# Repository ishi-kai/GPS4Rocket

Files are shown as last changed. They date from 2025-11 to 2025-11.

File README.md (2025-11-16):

# GPS System for Rocket
Commercially available GPS systems are not available for rockets.  
Therefore, we have created a full-scratch system.  

## Specification
- GPS Antenna
    - Use commercially available active antennas.
- [GPS Front End](https://github.com/ishi-kai/GPS4Rocket#GPS_FrontEnd)
    - MAX2769B-based GPS front-end board
- [Navigation Message Processor](https://github.com/ishi-kai/GPS4Rocket#Navigation_Message_Processor)
    - Operator to process IO data and navigation messages

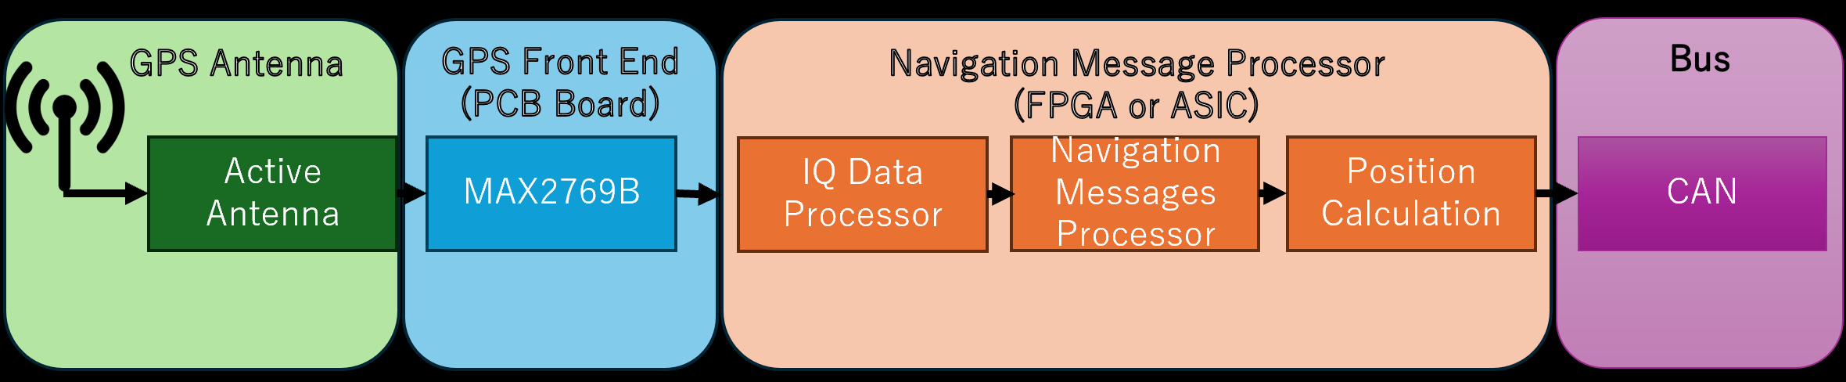
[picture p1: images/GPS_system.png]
GPS_System


## [GPS Front End Board](/GPS_FrontEnd/)
This is the hardware that handles the GPS front end. And This was created with KiCAD 9.  

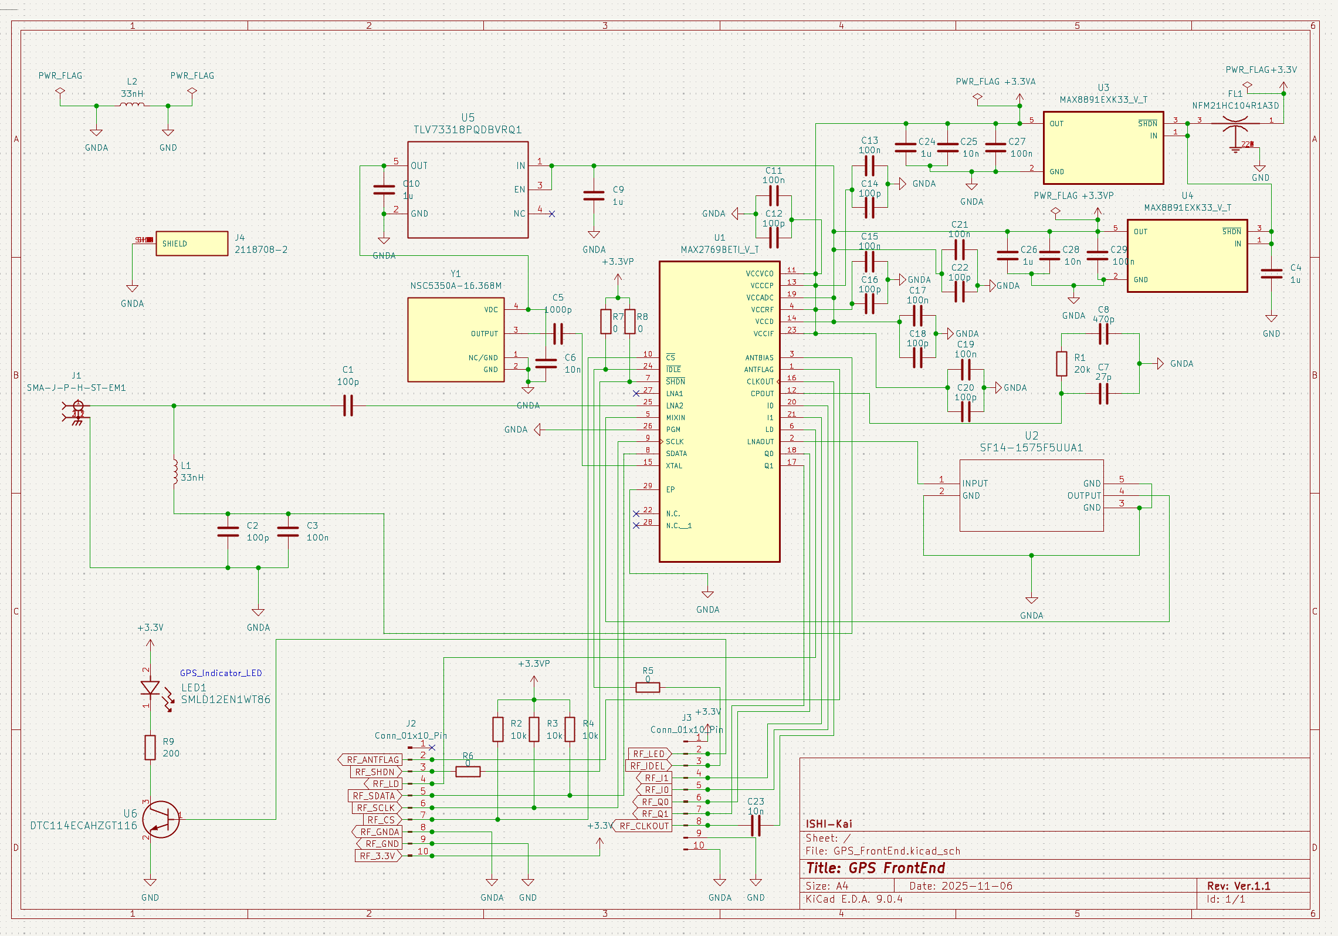
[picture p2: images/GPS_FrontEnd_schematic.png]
GPS_FrontEnd_schematic

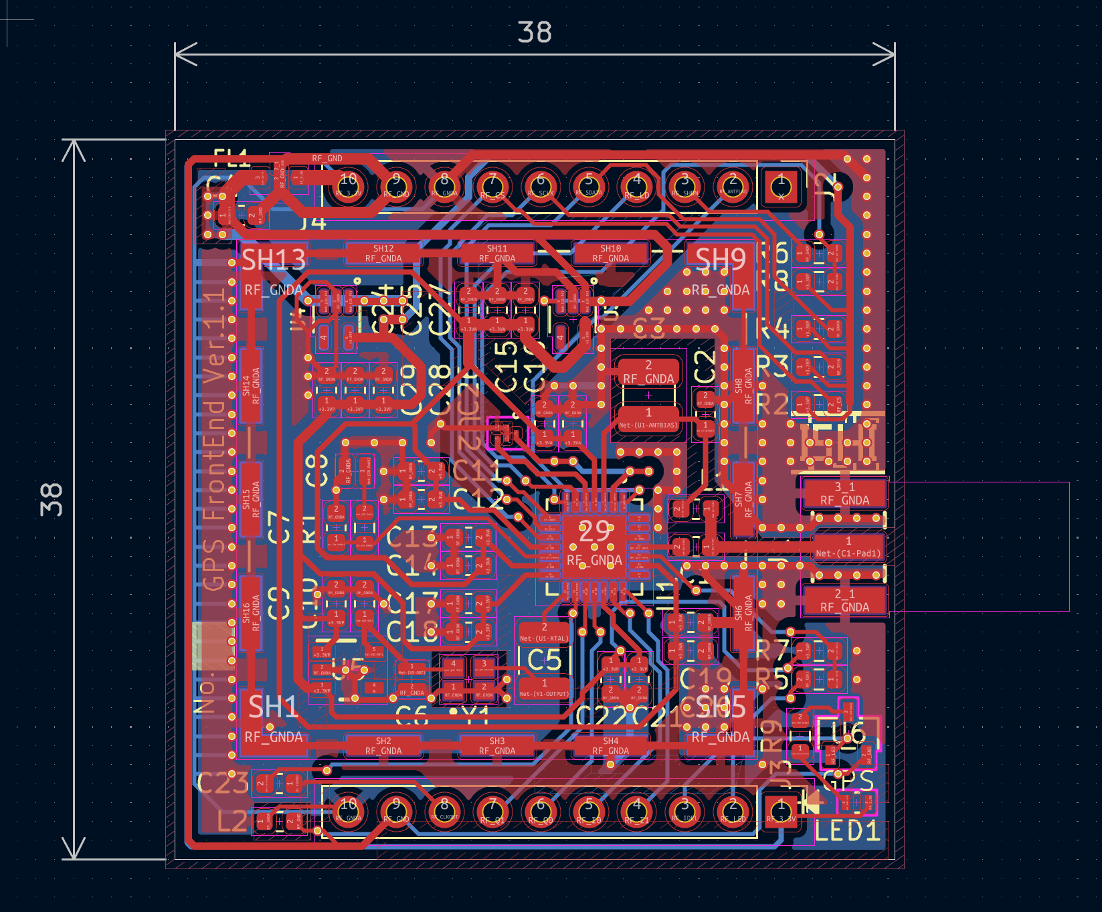
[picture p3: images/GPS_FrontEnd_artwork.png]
GPS_FrontEnd_artwork

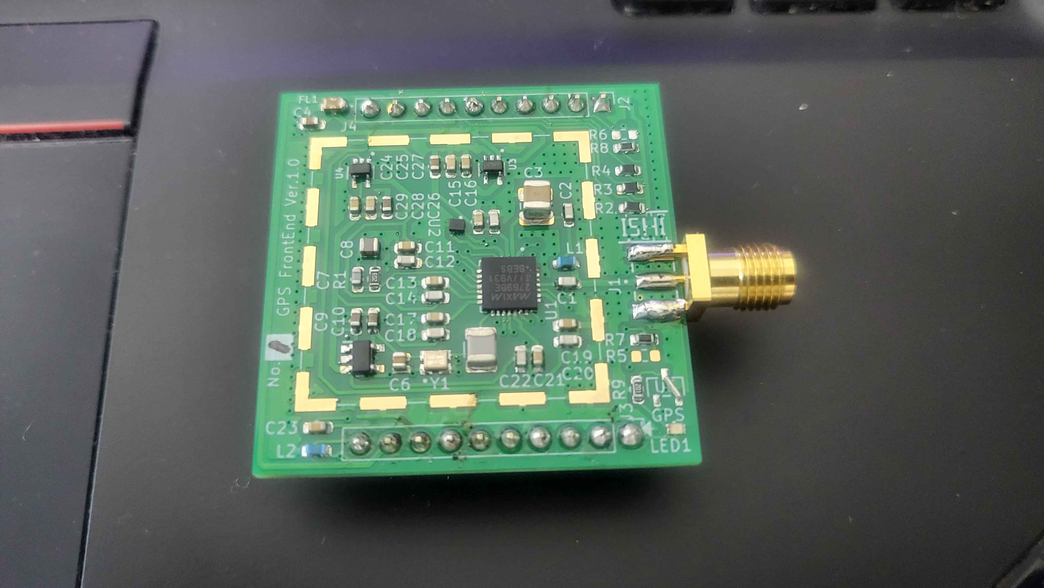
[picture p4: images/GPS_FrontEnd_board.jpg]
GPS_FrontEnd_board


## [Navigation Message Processor](/Navigation_Message_Processor/)

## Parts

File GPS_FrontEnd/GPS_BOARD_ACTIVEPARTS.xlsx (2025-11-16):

出荷時に原産国が変わる場合があります。
表示されているHTSUSおよびECCN情報は情報提供のみを目的としたもので、分類の正確性や信頼性を表明または保証するものではありません。すべての情報は「現状のまま」提供されており、予告なしに変更される場合があります。提供された情報の使用は、Digi-Keyに頼ることなく、ユーザーの責任において使用されるものとします。
インデックス | メーカー品番 | メーカー名 | 商品概要 | リードタイム | 入手性 | 在庫状況 | 仕損率 | リクエスト数量1 | パック数量1 | パックタイプ1 | Digi-Key品番1 | 単価1 | 金額1 | 最小発注数量1 | 客先参照品番 | リクエスト品番 | リードタイム（週） | データシート | 参照名 | 米国輸入関税 | メモ | 部品状況 | RoHSステータス | 湿度感度レベル（MSL） | ECCN | HTSUS | 原産国 | 環境規制対応 | オリジナル品番 | 画像 | 製品に関する注意事項
1 | MAX2769BETI/V+T | Analog Devices Inc./Maxim Integrated | RF RCVR GPS 1575.42MHZ 28TQFN |  | 1,961 | 在庫品目 |  | 1 | 1 | Cut Tape (CT) | 175-MAX2769BETI/V+TCT-ND | 11.32000 | $11.32 | 1 |  | 175-MAX2769BETI/V+TCT-ND | 10 | https://mm.digikey.com/Volume0/opasdata/d220001/medias/docus/1075/MAX2769B_PB.pdf |  | N/A |  | アクティブ | ROHS3対応 | 1（無制限） | 7A994 | 8542.39.0060 | Taiwan | https://www.maximintegrated.com/content/dam/files/design/emmi/rohs-certificate-of-compliance.pdf|https://www.maximintegrated.com/content/dam/files/design/emmi/reach-memo.pdf|https://www.maximintegrated.com/content/dam/files/design/emmi/red-phosphorous-statement.pdf | 175-MAX2769BETI/V+TCT-ND | https://mm.digikey.com/Volume0/opasdata/d220001/medias/images/6165/175%7E21-0140%7ETI%7E28.jpg | キャンセルや返品はできません.
2 | MAX8891EXK33/V+T | Analog Devices Inc./Maxim Integrated | IC REG LINEAR 3.3V 150MA SC-70-6 |  | 3,895 | 在庫品目 |  | 2 | 2 | Cut Tape (CT) | 175-MAX8891EXK33/V+TCT-ND | 2.11000 | $4.22 | 1 |  | 175-MAX8891EXK33/V+TCT-ND | 10 | https://www.analog.com/media/en/technical-documentation/data-sheets/MAX8891-MAX8892.pdf |  | N/A |  | アクティブ | ROHS3対応 | 1（無制限） | EAR99 | 8542.39.0090 | Malaysia | https://www.maximintegrated.com/content/dam/files/design/emmi/rohs-certificate-of-compliance.pdf|https://www.maximintegrated.com/content/dam/files/design/emmi/reach-memo.pdf | 175-MAX8891EXK33/V+TCT-ND | https://mm.digikey.com/Volume0/opasdata/d220001/medias/images/890/175-SC-70-5.jpg
3 | B39162B4348P810 | Qualcomm (RF front-end (RFFE) filters) | FILTER SAW 1.582GHZ 5-SMD |  | 778 | 在庫品目 |  | 1 | 1 | Cut Tape (CT) | B39162B4348P810CT-ND | 1.49000 | $1.49 | 1 |  | B39162B4348P810CT-ND | 8 | https://mm.digikey.com/Volume0/opasdata/d220001/medias/docus/925/B39162B4348P810.pdf |  | N/A |  | アクティブ | ROHS3対応 | 2A（4週間） | EAR99 | 8541.60.0080 | Singapore |  | B39162B4348P810CT-ND | https://mm.digikey.com/Volume0/opasdata/d220001/medias/images/2479/B7839%20Series.jpg
4 | SMA-J-P-H-ST-EM1 | Samtec Inc. | CONN SMA JACK STR 50OHM EDGE MNT | 2025年10月16日に入荷予定：1個 | 0 | 通常在庫 |  | 1 | 1 | Tray | SAM8857-ND | 2.43000 | $2.43 | 1 |  | SAM8857-ND | 6 | https://mm.digikey.com/Volume0/opasdata/d220001/medias/docus/6129/sma-j-p-x-st-em1-mkt.pdf |  | N/A |  | アクティブ | ROHS3対応 | 1（無制限） | EAR99 | 8536.69.4010 | Taiwan |  | SAM8857-ND | https://mm.digikey.com/Volume0/opasdata/d220001/medias/images/965/SMA-J-P-H-ST-EM1.JPG
5 | NSC5350A-16.368M | NDK (NIHON DEMPA KOGYO CO., LTD) | XTAL OSC TCXO 16.3680MHZ SMD |  | 867 | 在庫品目 |  | 1 | 1 | Cut Tape (CT) | 644-NSC5350A-16.368MCT-ND | 1.85000 | $1.85 | 1 |  | 644-NSC5350A-16.368MCT-ND | 24 | https://www.ndk.com/en/products/upload/lineup/pdf/NDKT03-00012_en.pdf |  | N/A |  | アクティブ | ROHS3対応 | 2（1年間） | EAR99 | 8542.39.0090 | Japan |  | 644-NSC5350A-16.368MCT-ND | https://mm.digikey.com/Volume0/opasdata/d220001/medias/images/55/MFG_NSC5350B-26M.jpg
6 | TLV73318PQDBVRQ1 | Texas Instruments | IC REG LINEAR 1.8V 300MA SOT23-5 |  | 16,868 | 在庫品目 |  | 1 | 1 | Cut Tape (CT) | 296-TLV73318PQDBVRQ1CT-ND | 0.45000 | $0.45 | 1 |  | 296-TLV73318PQDBVRQ1CT-ND | 12 | https://www.ti.com/general/docs/suppproductinfo.tsp?distId=10 |  | N/A |  | アクティブ | ROHS3対応 | 1（無制限） | EAR99 | 8542.39.0090 | Philippines |  | 296-TLV73318PQDBVRQ1CT-ND | https://mm.digikey.com/Volume0/opasdata/d220001/medias/images/5347/296%7E4214839%7EDBV%7E5.JPG
7 | SF14-1575F5UUA1 | KYOCERA AVX | FILTER SAW 1.575GHZ 5-SMD |  | 8,991 | 個在庫あり - 非在庫保有商品 |  | 1 | 1 | Cut Tape (CT) | 478-SF14-1575F5UUA1CT-ND | 0.61000 | $0.61 | 1 |  | 478-SF14-1575F5UUA1CT-ND | 16 | https://mm.digikey.com/Volume0/opasdata/d220001/medias/docus/6164/SF14_Saw_Filters.pdf |  | N/A |  | 生産中止品 | ROHS3対応 | 3（168時間） | 7A994 | 8541.60.0080 | Japan | https://ele.kyocera.com/assets/products/saw-device/environment/RoHS_SF14.pdf|https://ele.kyocera.com/assets/products/saw-device/environment/REACH_SF14.pdf | 478-SF14-1575F5UUA1CT-ND | https://mm.digikey.com/Volume0/opasdata/d220001/medias/images/2935/SF14%20Series.jpg
8 | DTC114ECAHZGT116 | Rohm Semiconductor | TRANS PREBIAS NPN 0.1A SST3 |  | 2,933 | 在庫品目 |  | 1 | 1 | Cut Tape (CT) | DTC114ECAHZGT116CT-ND | 0.17000 | $0.17 | 1 |  | DTC114ECAHZGT116CT-ND | 18 | https://www.rohm.co.jp/datasheet?p=DTC114ECAHZG&dist=Digi-key&media=referral&campaign=Digi-key |  | N/A |  | アクティブ | ROHS3対応 | 1（無制限） | EAR99 | 8541.21.0075 | South Korea | https://fscdn.rohm.com/en/techdata_basic/transistor/anti_whisker/TR_Whisker-e.pdf|https://fscdn.rohm.com/en/techdata_basic/transistor/esd/ESD_TR-DTC114ECAHZG-e.pdf|https://fscdn.rohm.com/en/techdata_basic/transistor/msl/TR_MSL-e.pdf | DTC114ECAHZGT116CT-ND | https://mm.digikey.com/Volume0/opasdata/d220001/medias/images/6347/846%7ESST3%7ESST%7E3.jpg
9 | 2118708-2 | TE Connectivity AMP Connectors | RF SHIELD 1.032"X1.032" SMD 1PC |  | 9,237 | 在庫品目 |  | 1 | 1 | Cut Tape (CT) | A126142CT-ND | 1.05000 | $1.05 | 1 |  | A126142CT-ND | 5 | https://www.te.com/commerce/DocumentDelivery/DDEController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 |  | N/A |  | アクティブ | RoHS対応 | 適用外 | EAR99 | 8529.90.9800 | China |  | A126142CT-ND | https://mm.digikey.com/Volume0/opasdata/d220001/medias/images/2521/MFG_2118708-2.jpg

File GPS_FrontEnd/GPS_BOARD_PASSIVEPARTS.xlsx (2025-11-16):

出荷時に原産国が変わる場合があります。
表示されているHTSUSおよびECCN情報は情報提供のみを目的としたもので、分類の正確性や信頼性を表明または保証するものではありません。すべての情報は「現状のまま」提供されており、予告なしに変更される場合があります。提供された情報の使用は、Digi-Keyに頼ることなく、ユーザーの責任において使用されるものとします。
インデックス | メーカー品番 | メーカー名 | 商品概要 | リードタイム | 入手性 | 在庫状況 | 仕損率 | リクエスト数量1 | パック数量1 | パックタイプ1 | Digi-Key品番1 | 単価1 | 金額1 | 最小発注数量1 | 客先参照品番 | リクエスト品番 | リードタイム（週） | データシート | 参照名 | 米国輸入関税 | メモ | 部品状況 | RoHSステータス | 湿度感度レベル（MSL） | ECCN | HTSUS | 原産国 | 環境規制対応 | オリジナル品番 | 画像 | 製品に関する注意事項
1 | SMLD12EN1WT86C | Rohm Semiconductor | LONG LIFE TYPE MINI-MOLD CHIP LE |  | 1,099 | 在庫品目 |  | 1 | 1 | Cut Tape (CT) | 846-SMLD12EN1WT86CCT-ND | 0.56000 | $0.56 | 1 |  | 846-SMLD12EN1WT86CCT-ND | 10 | https://www.rohm.com/datasheet?p=SMLD12EN1W(C)&dist=Digi-Key&media=referral&campaign=Digi-Key |  | N/A |  | アクティブ | ROHS3対応 | 3（168時間） | EAR99 | 8541.41.0000 | China |  | 846-SMLD12EN1WT86CCT-ND | https://mm.digikey.com/Volume0/opasdata/d220001/medias/images/5739/MFG_SMLD12EN1WT86C.jpg
2 | KGQ15ACG1H101FT | KYOCERA AVX | CAP CER 100PF 50V NP0 0603 |  | 7,700 | 在庫品目 |  | 8 | 8 | Cut Tape (CT) | 478-KGQ15ACG1H101FTCT-ND | 0.33000 | $2.64 | 1 |  | 478-KGQ15ACG1H101FTCT-ND | 10 | https://datasheets.kyocera-avx.com/KGQ-Series.pdf |  | N/A |  | アクティブ | ROHS3対応 | 1（無制限） | EAR99 | 8532.24.0020 | China |  | 478-KGQ15ACG1H101FTCT-ND | https://mm.digikey.com/Volume0/opasdata/d220001/medias/images/775/0603-%281608-Metric%29-0%2C91mm.jpg
3 | 1111X104KW500X | Passive Plus | CAP CER 0.1UF 50V X7R 1111 |  | 84 | 在庫品目 |  | 1 | 1 | Cut Tape (CT) | 4363-1111X104KW500XCT-ND | 4.79000 | $4.79 | 1 |  | 4363-1111X104KW500XCT-ND | 16 | https://passiveplus.com/products/fixed-capacitors/hi-q-low-esr-capacitors/ |  | N/A |  | アクティブ | ROHS3対応 | 1（無制限） | EAR99 | 8532.24.0020 | United States |  | 4363-1111X104KW500XCT-ND | https://mm.digikey.com/Volume0/opasdata/d220001/medias/images/4846/MFG_4363_1111x.jpg
4 | KGQ32DCG2A102FT | KYOCERA AVX | CAP CER 1000PF 100V C0G/NP0 1210 |  | 1,299 | 在庫品目 |  | 1 | 1 | Cut Tape (CT) | 478-KGQ32DCG2A102FTCT-ND | 0.70000 | $0.70 | 1 |  | 478-KGQ32DCG2A102FTCT-ND | 10 | https://datasheets.kyocera-avx.com/KGQ-Series.pdf |  | N/A |  | アクティブ | ROHS3対応 | 1（無制限） | EAR99 | 8532.24.0020 | El Salvador |  | 478-KGQ32DCG2A102FTCT-ND | https://mm.digikey.com/Volume0/opasdata/d220001/medias/images/935/1210-%283225-Metric%29-1%2C40mm-N-Code.jpg
5 | 0505X103MP500 | Passive Plus | CAP CER 10000PF 50V X7R 0505 |  | 1,400 | 在庫品目 |  | 1 | 1 | Cut Tape (CT) | 4363-0505X103MP500CT-ND | 3.89000 | $3.89 | 1 |  | 4363-0505X103MP500CT-ND | 16 | https://passiveplus.com/products/fixed-capacitors/hi-q-low-esr-capacitors/ |  | N/A |  | アクティブ | ROHS3対応 | 1（無制限） | EAR99 | 8532.24.0020 | United States |  | 4363-0505X103MP500CT-ND | https://mm.digikey.com/Volume0/opasdata/d220001/medias/images/3971/MFG_0505X.jpg
6 | KGQ15ACG1H270FT | KYOCERA AVX | CAP CER 27PF 50V NP0 0603 |  | 9,087 | 在庫品目 |  | 1 | 1 | Cut Tape (CT) | 478-KGQ15ACG1H270FTCT-ND | 0.33000 | $0.33 | 1 |  | 478-KGQ15ACG1H270FTCT-ND | 10 | https://datasheets.kyocera-avx.com/KGQ-Series.pdf |  | N/A |  | アクティブ | ROHS3対応 | 1（無制限） | EAR99 | 8532.24.0020 | El Salvador |  | 478-KGQ15ACG1H270FTCT-ND | https://mm.digikey.com/Volume0/opasdata/d220001/medias/images/775/0603-%281608-Metric%29-0%2C91mm.jpg
7 | 050521500471FQTAF9LM | Knowles Syfer | 0505 SIZE - 2 SINTERED SILVER WI |  | 2,406 | 在庫品目 |  | 1 | 1 | Cut Tape (CT) | 1608-050521500471FQTAF9LMCT-ND | 1.69000 | $1.69 | 1 |  | 1608-050521500471FQTAF9LMCT-ND | 11 | https://www.knowlescapacitors.com/getattachment/ac79327c-78b2-4790-b841-4541dcd9a291/High-Power-RF |  | N/A |  | アクティブ | ROHS3対応 | 1（無制限） | EAR99 | 8532.24.0020 | China |  | 1608-050521500471FQTAF9LMCT-ND | https://mm.digikey.com/Volume0/opasdata/d220001/medias/images/5701/MFG_CxxAH2R2x-xN-X1B.jpg
8 | KAM15AR70J105KT | KYOCERA AVX | 0603 X7R 1UF10% 6.3V AEC-Q200 |  | 11,890 | 在庫品目 |  | 5 | 5 | Cut Tape (CT) | 478-KAM15AR70J105KTCT-ND | 0.16000 | $0.80 | 1 |  | 478-KAM15AR70J105KTCT-ND | 20 | https://mm.digikey.com/Volume0/opasdata/d220001/medias/docus/5789/KAM15AR70J105KT%20Datasheet.pdf |  | N/A |  | アクティブ | ROHS3対応 | 1（無制限） | EAR99 | 8532.24.0020 | Japan |  | 478-KAM15AR70J105KTCT-ND | https://mm.digikey.com/Volume0/opasdata/d220001/medias/images/4845/478_0603-%281608-Metric%29-0%2C90mm.jpg | キャンセルや返品はできません.
9 | 0603YC104J4T4A | KYOCERA AVX | CAP CER 0.1UF 16V X7R 0603 |  | 5,180 | 在庫品目 |  | 8 | 8 | Cut Tape (CT) | 478-KAM15AR71C104JMCT-ND | 0.33000 | $2.64 | 1 |  | 478-KAM15AR71C104JMCT-ND | 12 | https://datasheets.kyocera-avx.com/AutoMLCC.pdf |  | N/A |  | アクティブ | ROHS3対応 | 1（無制限） | EAR99 | 8532.24.0020 | El Salvador |  | 478-KAM15AR71C104JMCT-ND | https://mm.digikey.com/Volume0/opasdata/d220001/medias/images/4845/478_0603-%281608-Metric%29-0%2C90mm.jpg
10 | KAM15AR71C103JT | KYOCERA AVX | CAP CER 10000PF 16V X7R 0603 |  | 3,275 | 在庫品目 |  | 3 | 3 | Cut Tape (CT) | 478-KAM15AR71C103JTCT-ND | 0.23000 | $0.69 | 1 |  | 478-KAM15AR71C103JTCT-ND | 12 | https://datasheets.kyocera-avx.com/AutoMLCCKAM.pdf |  | N/A |  | アクティブ | ROHS3対応 | 1（無制限） | EAR99 | 8532.24.0020 | El Salvador |  | 478-KAM15AR71C103JTCT-ND | https://mm.digikey.com/Volume0/opasdata/d220001/medias/images/4845/478_0603-%281608-Metric%29-0%2C90mm.jpg
11 | LQW18AS33NG0ZD | Murata Electronics | FIXED IND 33NH 600MA 220MOHM SMD |  | 18,952 | 在庫品目 |  | 2 | 2 | Cut Tape (CT) | 490-15818-1-ND | 0.15000 | $0.30 | 1 |  | 490-15818-1-ND | 16 | https://search.murata.co.jp/Ceramy/image/img/P02/JELF243A-9139.pdf |  | N/A |  | アクティブ | ROHS3対応 | 1（無制限） | EAR99 | 8504.50.8000 | Japan |  | 490-15818-1-ND | https://mm.digikey.com/Volume0/opasdata/d220001/medias/images/2530/0603%20%281608%20Metric%29%20Wirewound.jpg
12 | ERA-3ARW203V | Panasonic Electronic Components | RES SMD 20K OHM 0.05% 1/10W 0603 |  | 11,946 | 在庫品目 |  | 1 | 1 | Cut Tape (CT) | P20KBECT-ND | 0.44000 | $0.44 | 1 |  | P20KBECT-ND | 12 | https://industrial.panasonic.com/cdbs/www-data/pdf/RDM0000/AOA0000C307.pdf |  | N/A |  | アクティブ | ROHS3対応 | 1（無制限） | EAR99 | 8533.21.0030 | Japan | https://industrial.panasonic.com/cdbs/www-cgi/auto-publishing.cgi?type=ROSU&region=WW&layer=4&cd=AOA0026 | P20KBECT-ND | https://mm.digikey.com/Volume0/opasdata/d220001/medias/images/2391/10-0603%20Resistor.jpg
13 | ERJ-PA3F1002V | Panasonic Electronic Components | RES SMD 10K OHM 1% 1/3W 0603 |  | 53,902 | 在庫品目 |  | 3 | 3 | Cut Tape (CT) | P10KBYCT-ND | 0.14000 | $0.42 | 1 |  | P10KBYCT-ND | 12 | https://industrial.panasonic.com/cdbs/www-data/pdf/RDO0000/AOA0000C331.pdf |  | N/A |  | アクティブ | ROHS3対応 | 1（無制限） | EAR99 | 8533.21.0030 | Japan | https://industrial.panasonic.com/cdbs/www-cgi/auto-publishing.cgi?type=ROSU&region=WW&layer=4&cd=AOA0002 | P10KBYCT-ND | https://mm.digikey.com/Volume0/opasdata/d220001/medias/images/4322/cut-tape-render.jpg
14 | ERJ-H3G0R00V | Panasonic Electronic Components | RES 0 OHM JUMPER 1A 0603 |  | 6,751 | 在庫品目 |  | 2 | 2 | Cut Tape (CT) | 10-ERJ-H3G0R00VCT-ND | 0.10000 | $0.20 | 1 |  | 10-ERJ-H3G0R00VCT-ND | 12 | https://industrial.panasonic.com/cdbs/www-data/pdf/RDQ0000/ast-ind-151033.pdf |  | N/A |  | アクティブ | ROHS3対応 | 1（無制限） | EAR99 | 8533.21.0030 | Japan |  | 10-ERJ-H3G0R00VCT-ND | https://mm.digikey.com/Volume0/opasdata/d220001/medias/images/2642/MFG_Panasonic-ERJ-Hxx-Series-Resistors-Photo.jpg
15 | ERJ-3GEYJ201V | Panasonic Electronic Components | RES SMD 200 OHM 5% 1/10W 0603 |  | 459,412 | 在庫品目 |  | 1 | 1 | Cut Tape (CT) | P200GCT-ND | 0.10000 | $0.10 | 1 |  | P200GCT-ND | 12 | https://industrial.panasonic.com/ww/products/pt/general-purpose-chip-resistors/models/ERJ3GEYJ201V |  | N/A |  | アクティブ | ROHS3対応 | 1（無制限） | EAR99 | 8533.21.0030 | China | https://industrial.panasonic.com/cdbs/www-cgi/auto-publishing.cgi?type=ROSU&region=WW&layer=4&cd=AOA0002 | P200GCT-ND | https://mm.digikey.com/Volume0/opasdata/d220001/medias/images/2606/MFG_ERJ-P6W%20Series.jpg
16 | NFM21HC104R1A3D | Murata Electronics | CAP FEEDTHRU 0.1UF 20% 10V 0805 |  | 7,950 | 在庫品目 |  | 1 | 1 | Cut Tape (CT) | 490-11838-1-ND | 0.29000 | $0.29 | 1 |  | 490-11838-1-ND | 12 | https://search.murata.co.jp/Ceramy/image/img/A01X/G101/ENG/NFM21HC104R1A3-01.pdf |  | N/A |  | アクティブ | ROHS3対応 | 1（無制限） | EAR99 | 8532.24.0020 | Japan |  | 490-11838-1-ND | https://mm.digikey.com/Volume0/opasdata/d220001/medias/images/4999/EMIFIL-NFM21-3PC-Pad-Black.JPG

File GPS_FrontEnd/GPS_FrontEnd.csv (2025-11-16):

Reference | Qty | Value | DNP | Exclude from BOM | Exclude from Board | Footprint | Datasheet
C1,C2,C12,C14,C16,C18,C20,C22 | 8 | 100p |  |  |  | Capacitor_SMD:C_0603_1608Metric | ~
C3 | 1 | 100n |  |  |  | GPS_FrontEnd:C_1111_2828Metric | ~
C4,C9,C10,C24,C26 | 5 | 1u |  |  |  | Capacitor_SMD:C_0603_1608Metric | ~
C5 | 1 | 1000p |  |  |  | Capacitor_SMD:C_1210_3225Metric | ~
C6 | 1 | 10n |  |  |  | GPS_FrontEnd:C_0505_1313Metric | ~
C7 | 1 | 27p |  |  |  | Capacitor_SMD:C_0603_1608Metric | ~
C8 | 1 | 470p |  |  |  | GPS_FrontEnd:C_0505_1313Metric | ~
C11,C13,C15,C17,C19,C21,C27,C29 | 8 | 100n |  |  |  | Capacitor_SMD:C_0603_1608Metric | ~
C23,C25,C28 | 3 | 10n |  |  |  | Capacitor_SMD:C_0603_1608Metric | ~
FL1 | 1 | NFM21HC104R1A3D |  |  |  | GPS_FrontEnd:FIL_NFM21HC104R1A3D
J1 | 1 | SMA-J-P-H-ST-EM1 |  |  |  | GPS_FrontEnd:SAMTEC_SMA-J-P-H-ST-EM1
J2,J3 | 2 | Conn_01x10_Pin |  |  |  | Connector_PinHeader_2.54mm:PinHeader_1x10_P2.54mm_Vertical | ~
J4 | 1 | 2118708-2 |  |  |  | GPS_FrontEnd:TE_2118708-2
L1,L2 | 2 | 33nH |  |  |  | Inductor_SMD:L_0603_1608Metric | ~
LED1 | 1 | SMLD12EN1WT86 |  |  |  | GPS_FrontEnd:SMLD12EN1WT86 | SMLD12EN1WT86
R1 | 1 | 20k |  |  |  | Resistor_SMD:R_0603_1608Metric | ~
R2,R3,R4 | 3 | 10k |  |  |  | Resistor_SMD:R_0603_1608Metric | ~
R5,R6 | 2 | 0 |  |  |  | Resistor_SMD:R_0603_1608Metric | ~ | 実装除外
R7,R8 | 2 | 0 |  |  |  | Resistor_SMD:R_0603_1608Metric | ~
R9 | 1 | 200 |  |  |  | Resistor_SMD:R_0603_1608Metric | ~
U1 | 1 | MAX2769BETI_V_T |  |  |  | GPS_FrontEnd:QFN50P500X500X80-29N
U2 | 1 | SF14-1575F5UUA1 |  |  |  | GPS_FrontEnd:SO4_1411-SAW_1p1x1p4_KAV | SF14-1575F5UUA1
U3,U4 | 2 | MAX8891EXK33_V_T |  |  |  | GPS_FrontEnd:SOT65P210X110-5N
U5 | 1 | TLV73318PQDBVRQ1 |  |  |  | GPS_FrontEnd:DBV0005A_N | https://www.ti.com/lit/gpn/tlv733p-q1
U6 | 1 | DTC114ECAHZGT116 |  |  |  | GPS_FrontEnd:TRANS_DTCZCAHZGT_ROM | DTC114ECAHZGT116
Y1 | 1 | NSC5350A-16.368M |  |  |  | GPS_FrontEnd:OSC_TX22-18025S-19.200-R

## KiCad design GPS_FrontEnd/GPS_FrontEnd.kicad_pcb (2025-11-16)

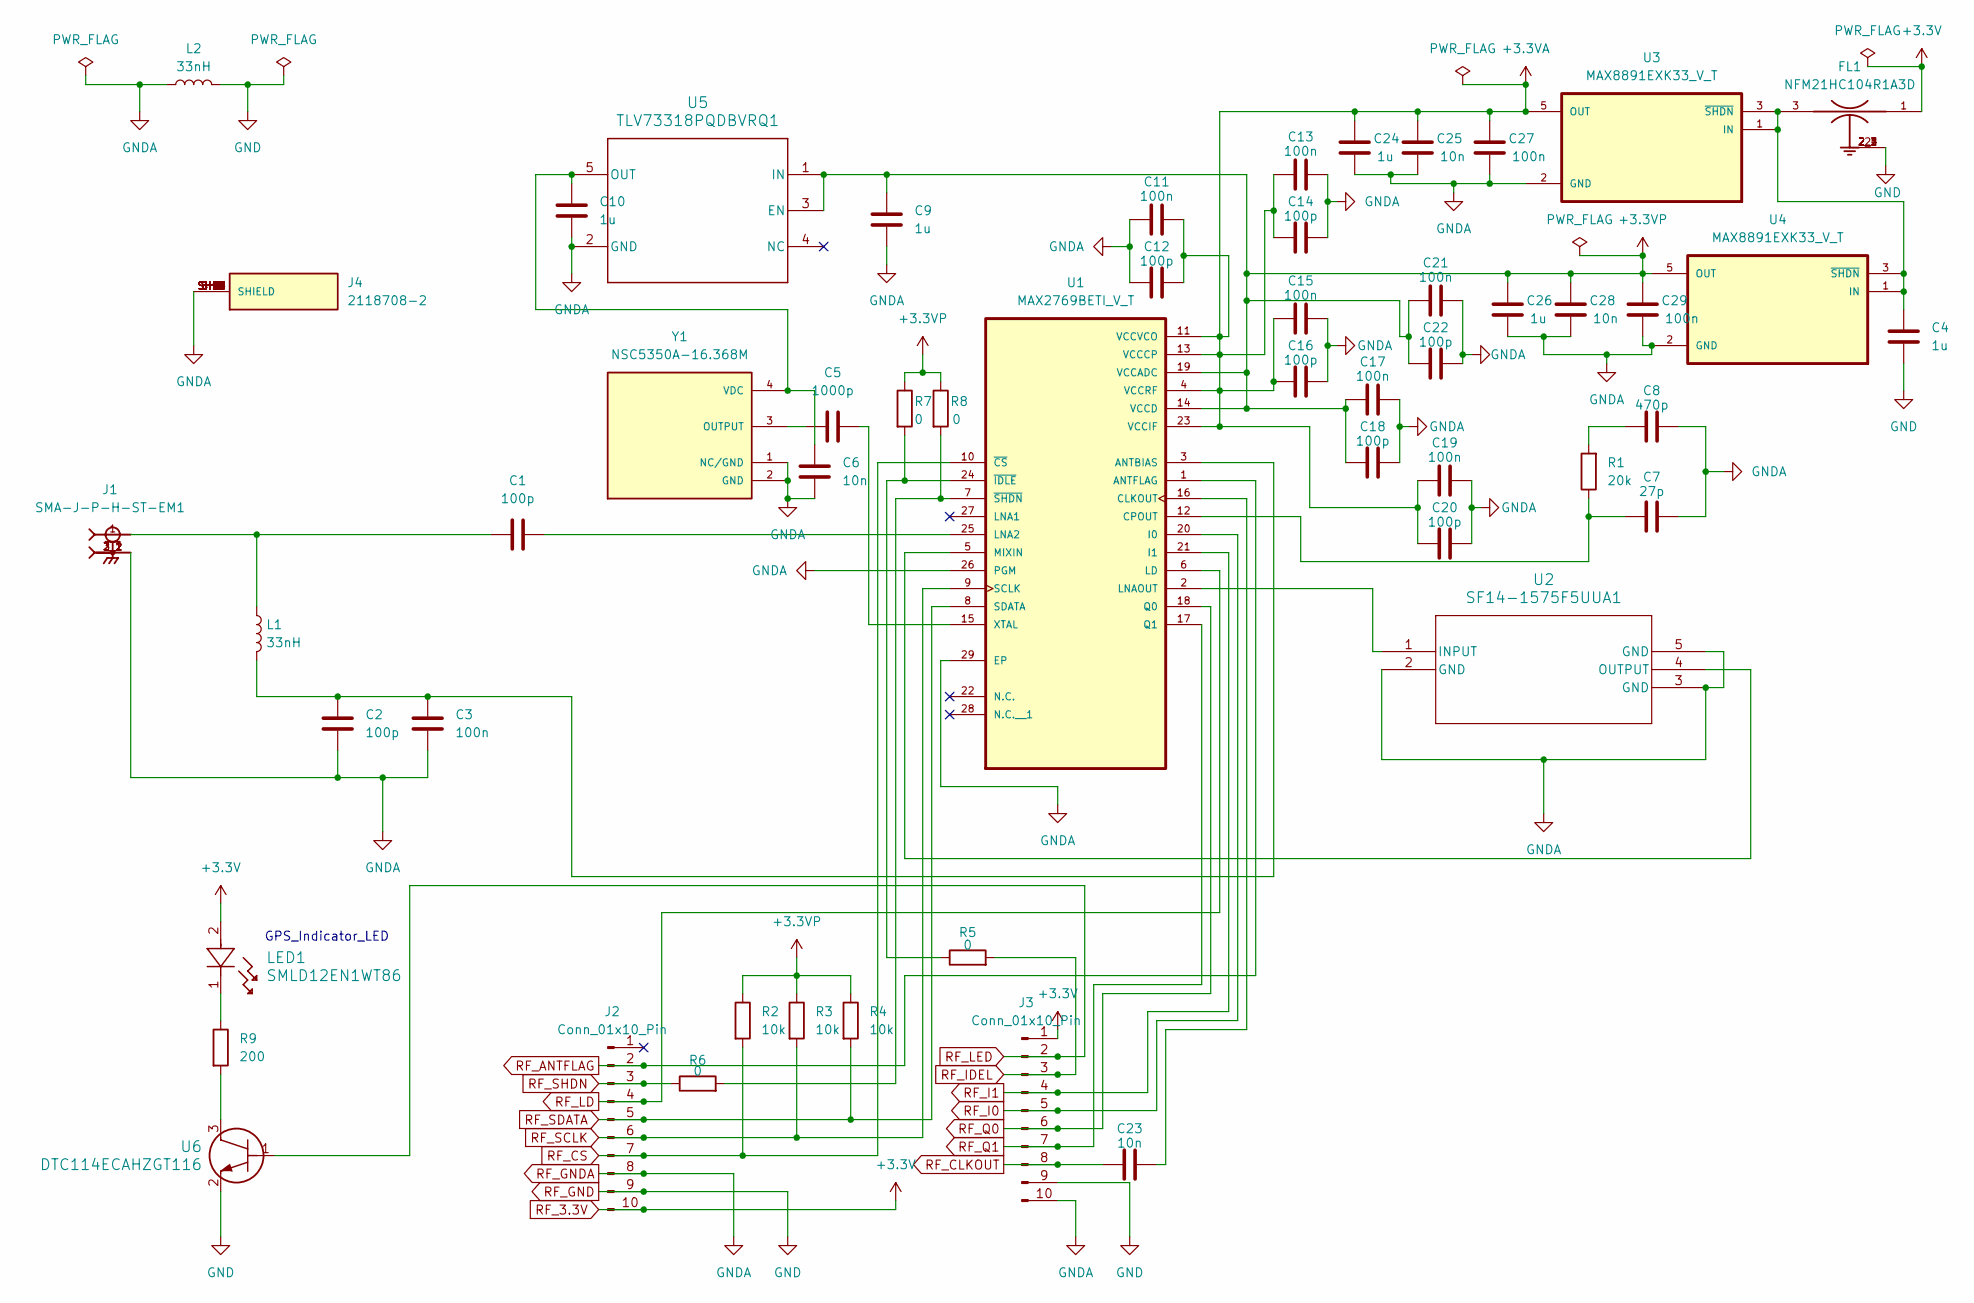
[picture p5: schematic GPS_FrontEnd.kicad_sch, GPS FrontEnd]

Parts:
C1, C2, C12, C14, C16, C18, C20, C22: 100p; C_0603_1608Metric
C3: 100n; C_1111_2828Metric
C4, C9, C10, C24, C26: 1u; C_0603_1608Metric
C5: 1000p; C_1210_3225Metric
C6: 10n; C_0505_1313Metric
C7: 27p; C_0603_1608Metric
C8: 470p; C_0505_1313Metric
C11, C13, C15, C17, C19, C21, C27, C29: 100n; C_0603_1608Metric
C23, C25, C28: 10n; C_0603_1608Metric
FL1: NFM21HC104R1A3D; FIL_NFM21HC104R1A3D
J1: SMA-J-P-H-ST-EM1; SAMTEC_SMA-J-P-H-ST-EM1; PARTREV G
J2, J3: Conn_01x10_Pin; PinHeader_1x10_P2.54mm_Vertical
J4: 2118708-2; TE_2118708-2; PARTREV A2
L1, L2: 33nH; L_0603_1608Metric
LED1: SMLD12EN1WT86
R1: 20k; R_0603_1608Metric
R2, R3, R4: 10k; R_0603_1608Metric
R5, R6, R7, R8: 0; R_0603_1608Metric
R9: 200; R_0603_1608Metric
U1: MAX2769BETI_V_T; QFN50P500X500X80-29N
U2: SF14-1575F5UUA1; SO4_1411-SAW_1p1x1p4_KAV
U3, U4: MAX8891EXK33_V_T; SOT65P210X110-5N
U5: TLV73318PQDBVRQ1; DBV0005A_N
U6: DTC114ECAHZGT116; TRANS_DTCZCAHZGT_ROM
Y1: NSC5350A-16.368M; OSC_TX22-18025S-19.200-R; PARTREV Nov 07, 2023

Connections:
+3.3VA: C11.2, C12.2, C13.2, C14.2, C15.1, C16.1, C19.1, C20.1, C24.1, C25.1, C27.1, U1.4 (VCCRF), U1.11 (VCCVCO), U1.13 (VCCCP), U1.23 (VCCIF), U3.5 (OUT)
+3.3VP: C9.1, C17.2, C18.2, C21.1, C22.1, C26.1, C28.1, C29.1, R2.1, R3.1, R4.1, R7.1, R8.1, U1.14 (VCCD), U1.19 (VCCADC), U4.5 (OUT), U5.1 (IN), U5.3 (EN)
unnamed: C1.1, J1.1, L1.1
unnamed: C8.1, R1.2
unnamed: LED1.1, R9.1
unnamed: R9.2, U6.3
unnamed: C2.1, C3.1, L1.2, U1.3 (ANTBIAS)
unnamed: C23.2, U1.16 (CLKOUT)
unnamed: C7.1, R1.1, U1.12 (CPOUT)
unnamed: C1.2, U1.25 (LNA2)
unnamed: U1.2 (LNAOUT), U2.1 (INPUT)
unnamed: U1.5 (MIXIN), U2.4 (OUTPUT)
unnamed: C5.2, U1.15 (XTAL)
unnamed: R5.1, R7.2, U1.24 (~IDLE)
unnamed: R6.2, R8.2, U1.7 (~SHDN)
unnamed: C4.1, FL1.3, U3.1 (IN), U3.3 (~SHDN), U4.1 (IN), U4.3 (~SHDN)
unnamed: C6.1, C10.1, U5.5 (OUT), Y1.4 (VDC)
unnamed: C5.1, Y1.3 (OUTPUT)
RF_3.3V: FL1.1, J2.10, J3.1, LED1.2
RF_ANTFLAG: J2.2, U1.1 (ANTFLAG)
RF_CLKOUT: C23.1, J3.8
RF_CS: J2.7, R2.2, U1.10 (~CS)
RF_GND: C4.2, FL1.2, FL1.2_1, FL1.2_2, FL1.2_3, FL1.2_4, J2.9, J3.9, L2.2, U6.2
RF_GNDA: C2.2, C3.2, C6.2, C7.2, C8.2, C9.2, C10.2, C11.1, C12.1, C13.1, C14.1, C15.2, C16.2, C17.1, C18.1, C19.2, C20.2, C21.2, C22.2, C24.2, C25.2, C26.2, C27.2, C28.2, C29.2, J1.2_1, J1.2_2, J1.3_1, J1.3_2, J2.8, J3.10, J4.SH1 (SHIELD), J4.SH2 (SHIELD), J4.SH3 (SHIELD), J4.SH4 (SHIELD), J4.SH5 (SHIELD), J4.SH6 (SHIELD), J4.SH7 (SHIELD), J4.SH8 (SHIELD), J4.SH9 (SHIELD), J4.SH10 (SHIELD), J4.SH11 (SHIELD), J4.SH12 (SHIELD), J4.SH13 (SHIELD), J4.SH14 (SHIELD), J4.SH15 (SHIELD), J4.SH16 (SHIELD), L2.1, U1.26 (PGM), U1.29 (EP), U2.2 (GND), U2.3 (GND), U2.5 (GND), U3.2 (GND), U4.2 (GND), U5.2 (GND), Y1.1 (NC/GND), Y1.2 (GND)
RF_I0: J3.5, U1.20 (I0)
RF_I1: J3.4, U1.21 (I1)
RF_IDEL: J3.3, R5.2
RF_LD: J2.4, U1.6 (LD)
RF_LED: J3.2, U6.1
RF_Q0: J3.6, U1.18 (Q0)
RF_Q1: J3.7, U1.17 (Q1)
RF_SCLK: J2.6, R3.2, U1.9 (SCLK)
RF_SDATA: J2.5, R4.2, U1.8 (SDATA)
RF_SHDN: J2.3, R6.1

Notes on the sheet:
GPS_Indicator_LED

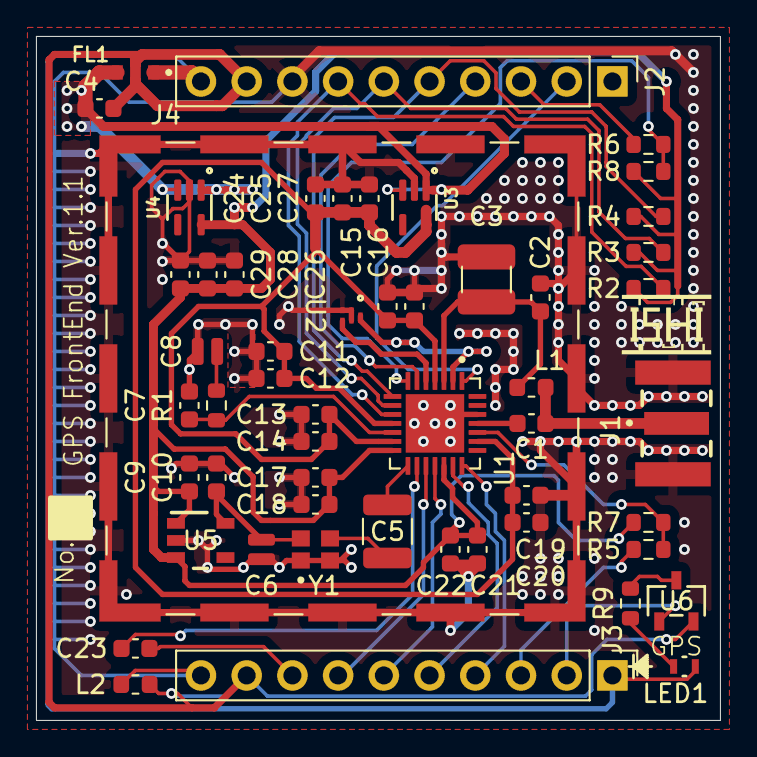
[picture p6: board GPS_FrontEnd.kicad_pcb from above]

Board: 2 copper layers, 38.0 x 38.0 mm, 53 parts (0 on the bottom side), 34 nets.
